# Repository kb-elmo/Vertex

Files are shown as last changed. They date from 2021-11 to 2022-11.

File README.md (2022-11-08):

# Vertex

[][cc-by-nc-sa]<a href="https://ko-fi.com/kb_elmo">kofibadge</a>

### 3D printed Vortex 40% inspired screwless exterior, top-mount keyboard

header

### This design has some flaws!
#### Use at your own risk

---

[STEP files for the case](case/)

[KiCAD PCB files](pcb/)

[Gerbers for PCB production](pcb/gerbers/)

[JLCPCB BOM](pcb/fab/vertex_bom_jlc.csv)

[JLCPCB CPL](pcb/fab/vertex_cpl_jlc.csv)

[Vial-QMK firmware](firmware/)

---

This work is licensed under a
[Creative Commons Attribution-NonCommercial-ShareAlike 4.0 International License][cc-by-nc-sa].

[][cc-by-nc-sa]

[cc-by-nc-sa]: http://creativecommons.org/licenses/by-nc-sa/4.0/
[cc-by-nc-sa-image]: https://licensebuttons.net/l/by-nc-sa/4.0/88x31.png
[cc-by-nc-sa-shield]: https://img.shields.io/badge/License-CC%20BY--NC--SA%204.0-lightgrey.svg

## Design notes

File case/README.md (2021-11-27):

# Vertex case

### These files are meant for 3D printing only! 

They are not suitable for CNC machining and trying to use them for that will most likely result in failure of the parts.

For assembly you need 4x m2x10mm screws for the case and 8x m2x8mm screws to mount the plate.  
The three pieces that make the bottom half of the case have tabs on the sides for glueing them together.  
It's not strictly necessary to do this but it helps with the overall rigidity of the case assembly.

---

### Supported layouts

Right now there is only one plate available.  
More alternative options will be added later.

The currently supported layout looks like this.
layout1

<!--Plate 2  
<img src="https://i.imgur.com/FzC2Qn9.png" alt="layout2"/>

Plate 3  
<img src="https://i.imgur.com/ZxjCJdc.png" alt="layout3"/>
-->

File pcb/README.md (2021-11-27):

# Vertex PCB

### Features

- Powered by an Atmega32u2
- Basic ESD and overvoltage protection
- USB type-C port for a detachable cable
- Multiple layout options (see below)
- Fully programmable using [QMK](https://qmk.fm) and [Vial](https://get.vial.today)

---

### Supported layouts

layout1

The two different lengths spacebars can be swapped.

---

### Preview

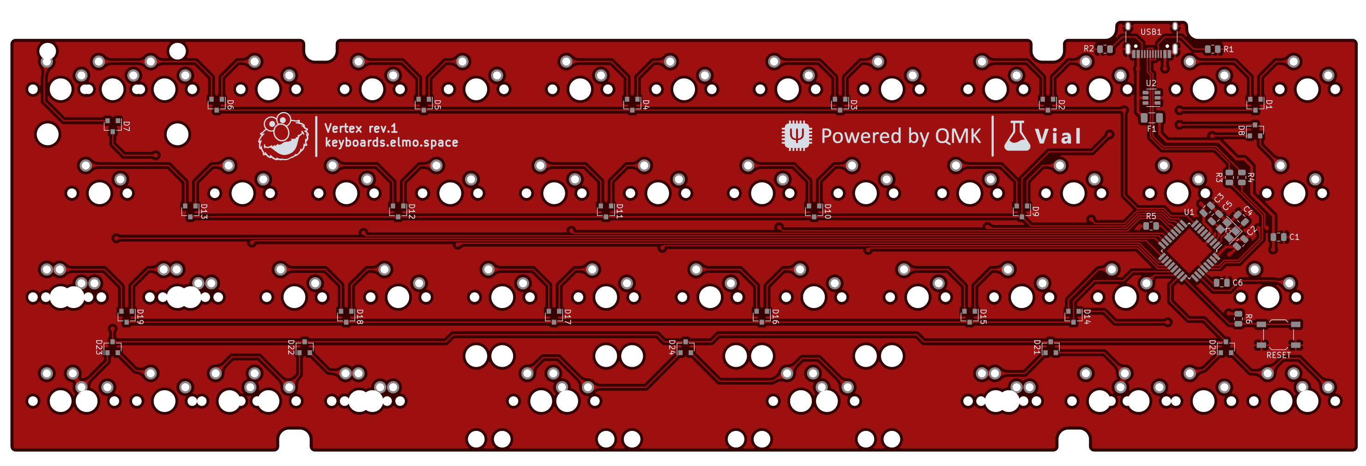
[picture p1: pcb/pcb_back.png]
pcb_back

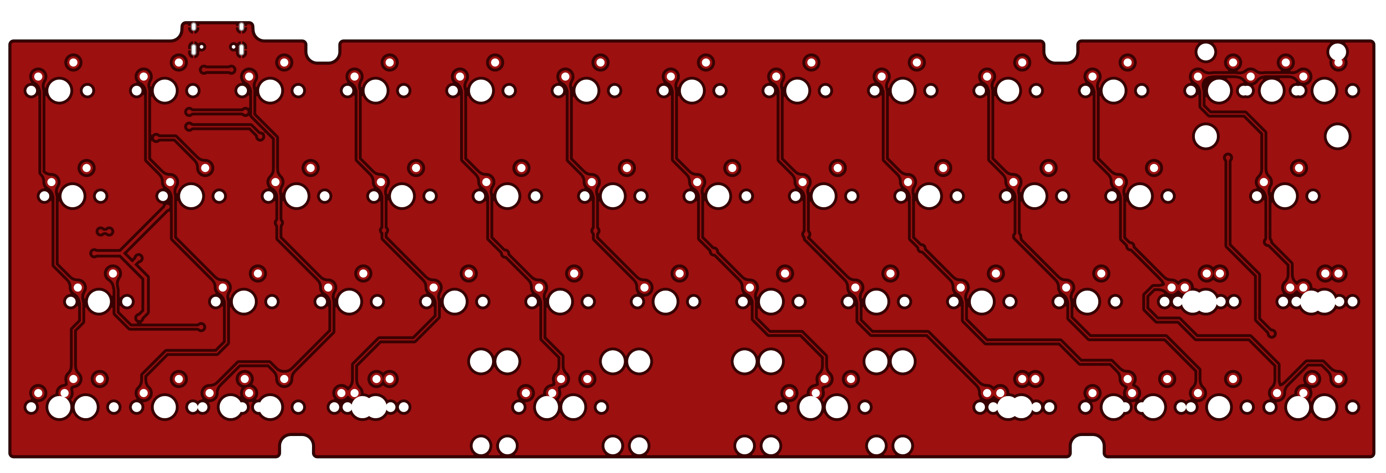
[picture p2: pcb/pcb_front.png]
pcb_front


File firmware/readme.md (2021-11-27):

# Vertex

vertex

3D printed Vortex 40% inspired screwless exterior, top-mount keyboard

* Keyboard Maintainer: [kb-elmo](https://github.com/kb-elmo)
* Hardware Supported: Vertex rev.1
* Hardware Availability: [Open source project](https://github.com/kb-elmo/Vertex)

Make example for this keyboard (after setting up your build environment):

    make kb_elmo/vertex:default

Flashing example for this keyboard:

    make kb_elmo/vertex:default:flash

See the [build environment setup](https://docs.qmk.fm/#/getting_started_build_tools) and the [make instructions](https://docs.qmk.fm/#/getting_started_make_guide) for more information. Brand new to QMK? Start with our [Complete Newbs Guide](https://docs.qmk.fm/#/newbs).

## Bootloader

* **Bootmagic reset**: Hold down the top left key and plug in the keyboard
* **Physical reset button**: Briefly press the button labeled "Reset" on the back of the PCB
* **Keycode in layout**: Press the key mapped to `RESET` if it is available

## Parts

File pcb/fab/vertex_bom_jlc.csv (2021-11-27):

Comment | Designator | Footprint | LCSC Part #
10uF | C1 | C_0805_2012Metric | C91245
0.1uF | C2,C3 | C_0805_2012Metric | C49678
22pF | C4,C5 | C_0805_2012Metric | C1804
1uF | C6 | C_0805_2012Metric | C28323
D_Small | D5,D4,D3,D2,D6,D8,D12,D11,D10,D9,D13,D14,D18,D17,D16,D15,D19,D20,D22,D21,D23,D24,D7,D1 | D_SOT-23_ANK_norm | C68978
Polyfuse_Small | F1 | Fuse_1206_3216Metric | C69688
5.1k | R1,R2 | R_0805_2012Metric | C27834
22 | R3,R4 | R_0805_2012Metric | C17561
10k | R5,R6 | R_0805_2012Metric | C17414
SW_Push | RESET | SW_SPST_TL3342 | C318884
ATmega32U2-AU | U1 | TQFP-32_7x7mm_P0.8mm | C618733
SRV05-4 | U2 | SOT-23-6 | C85364
USB_C_Receptacle_USB2.0 | USB1 | USB_C_Receptacle_HRO_TYPE-C-31-M-12 | C165948
Crystal_GND24_Small | X1 | Crystal_SMD_3225-4Pin_3.2x2.5mm | C13738

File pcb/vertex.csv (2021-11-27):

Comment | Designator | Footprint | LCSC
10uF | C1 | Capacitor_SMD:C_0805_2012Metric | C91245
0.1uF | C2,C3 | Capacitor_SMD:C_0805_2012Metric | C49678
22pF | C4,C5 | Capacitor_SMD:C_0805_2012Metric | C1804
1uF | C6 | Capacitor_SMD:C_0805_2012Metric | C28323
D_Small | D1,D2,D3,D4,D5,D6,D7,D8,D9,D10,D11,D12,D13,D14,D15,D16,D17,D18,D19,D20,D21,D22,D23,D24 | custom_parts:D_SOT-23_ANK_norm | C68978
Polyfuse_Small | F1 | Fuse:Fuse_1206_3216Metric | C69688
MX-NoLED | MX14,MX37,MX39,MX40,MX43,MX44,MX66 | MX_Only:MXOnly-1.25U-NoLED
MX-NoLED | MX1,MX2,MX3,MX4,MX5,MX6,MX7,MX8,MX9,MX10,MX11,MX12,MX13,MX15,MX16,MX17,MX18,MX19,MX20,MX21,MX22,MX23,MX24,MX27,MX28,MX29,MX30,MX31,MX32,MX33,MX34,MX35,MX36,MX46,MX47,MX48,MX49,MX50,MX51,MX52,MX53,MX67 | MX_Only:MXOnly-1U-NoLED
MX-NoLED | MX25,MX26 | MX_Only:MXOnly-1.75U-NoLED
MX-NoLED | MX38,MX45 | MX_Only:MXOnly-1.5U-NoLED
MX-NoLED | MX41,MX54 | MX_Only:MXOnly-2.75U-ReversedStabilizers-NoLED
MX-NoLED | MX42,MX55 | MX_Only:MXOnly-2.25U-ReversedStabilizers-NoLED
MX-NoLED | MX60 | MX_Only:MXOnly-2U-NoLED
5.1k | R1,R2 | Resistor_SMD:R_0805_2012Metric | C27834
22 | R3,R4 | Resistor_SMD:R_0805_2012Metric | C17561
10k | R5,R6 | Resistor_SMD:R_0805_2012Metric | C17414
SW_Push | RESET1 | Button_Switch_SMD:SW_SPST_TL3342 | C318884
ATmega32U2-AU | U1 | Package_QFP:TQFP-32_7x7mm_P0.8mm | C618733
SRV05-4 | U2 | Package_TO_SOT_SMD:SOT-23-6 | C85364
USB_C_Receptacle_USB2.0 | USB1 | Connector_USB:USB_C_Receptacle_HRO_TYPE-C-31-M-12 | C165948
Crystal_GND24_Small | X1 | Crystal:Crystal_SMD_3225-4Pin_3.2x2.5mm | C13738

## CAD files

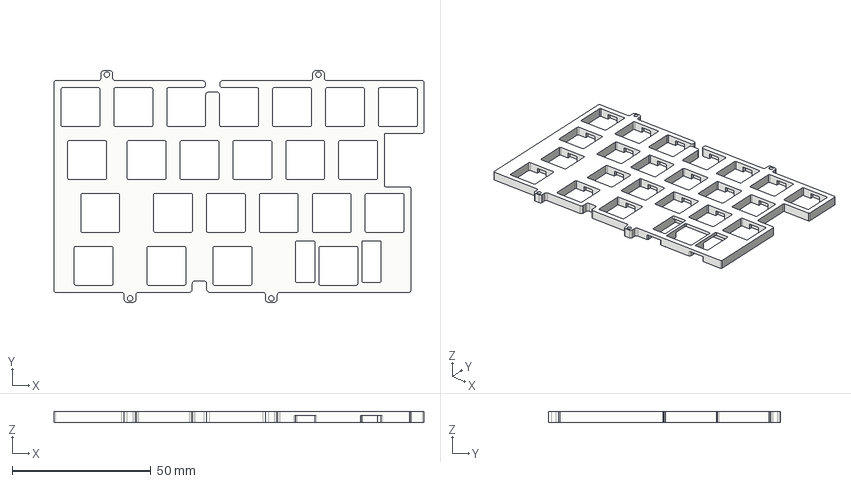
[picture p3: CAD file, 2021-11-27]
case/plate_left.step
133.2 x 83.4 x 4.00 mm

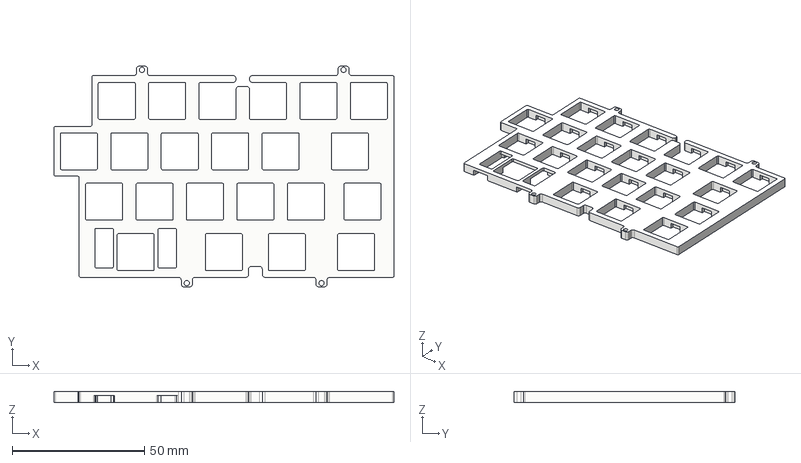
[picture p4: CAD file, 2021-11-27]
case/plate_right.step
128.5 x 83.4 x 4.00 mm

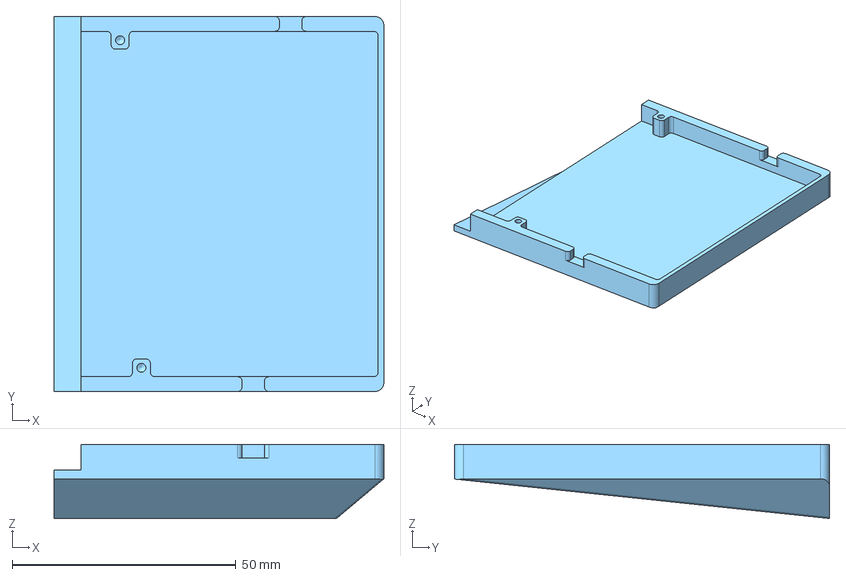
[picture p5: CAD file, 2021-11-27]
case/bottom_right.step
73.7 x 83.8 x 16.5 mm

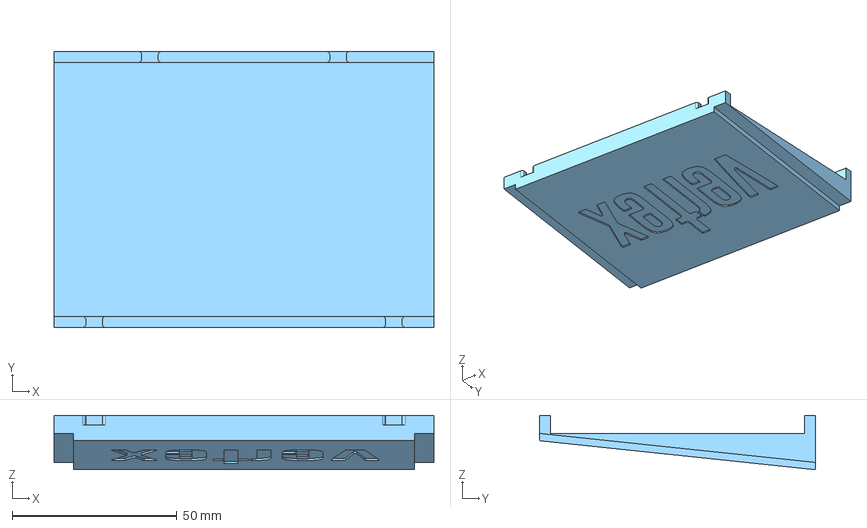
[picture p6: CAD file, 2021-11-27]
case/bottom_center.step
115.5 x 83.8 x 16.5 mm

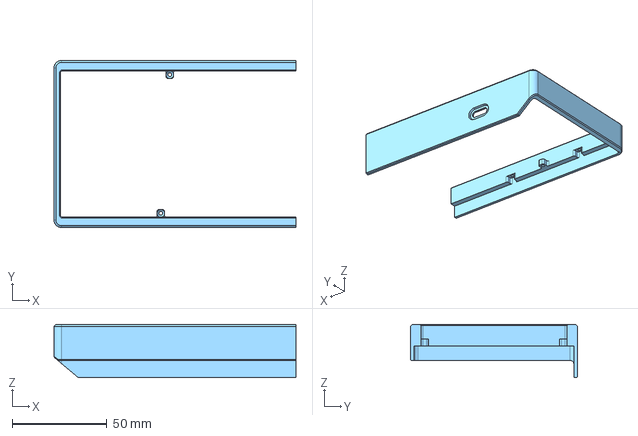
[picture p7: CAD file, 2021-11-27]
case/top_left.step
127.7 x 88.2 x 28.0 mm

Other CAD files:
case/bottom_left.step
case/top_right.step

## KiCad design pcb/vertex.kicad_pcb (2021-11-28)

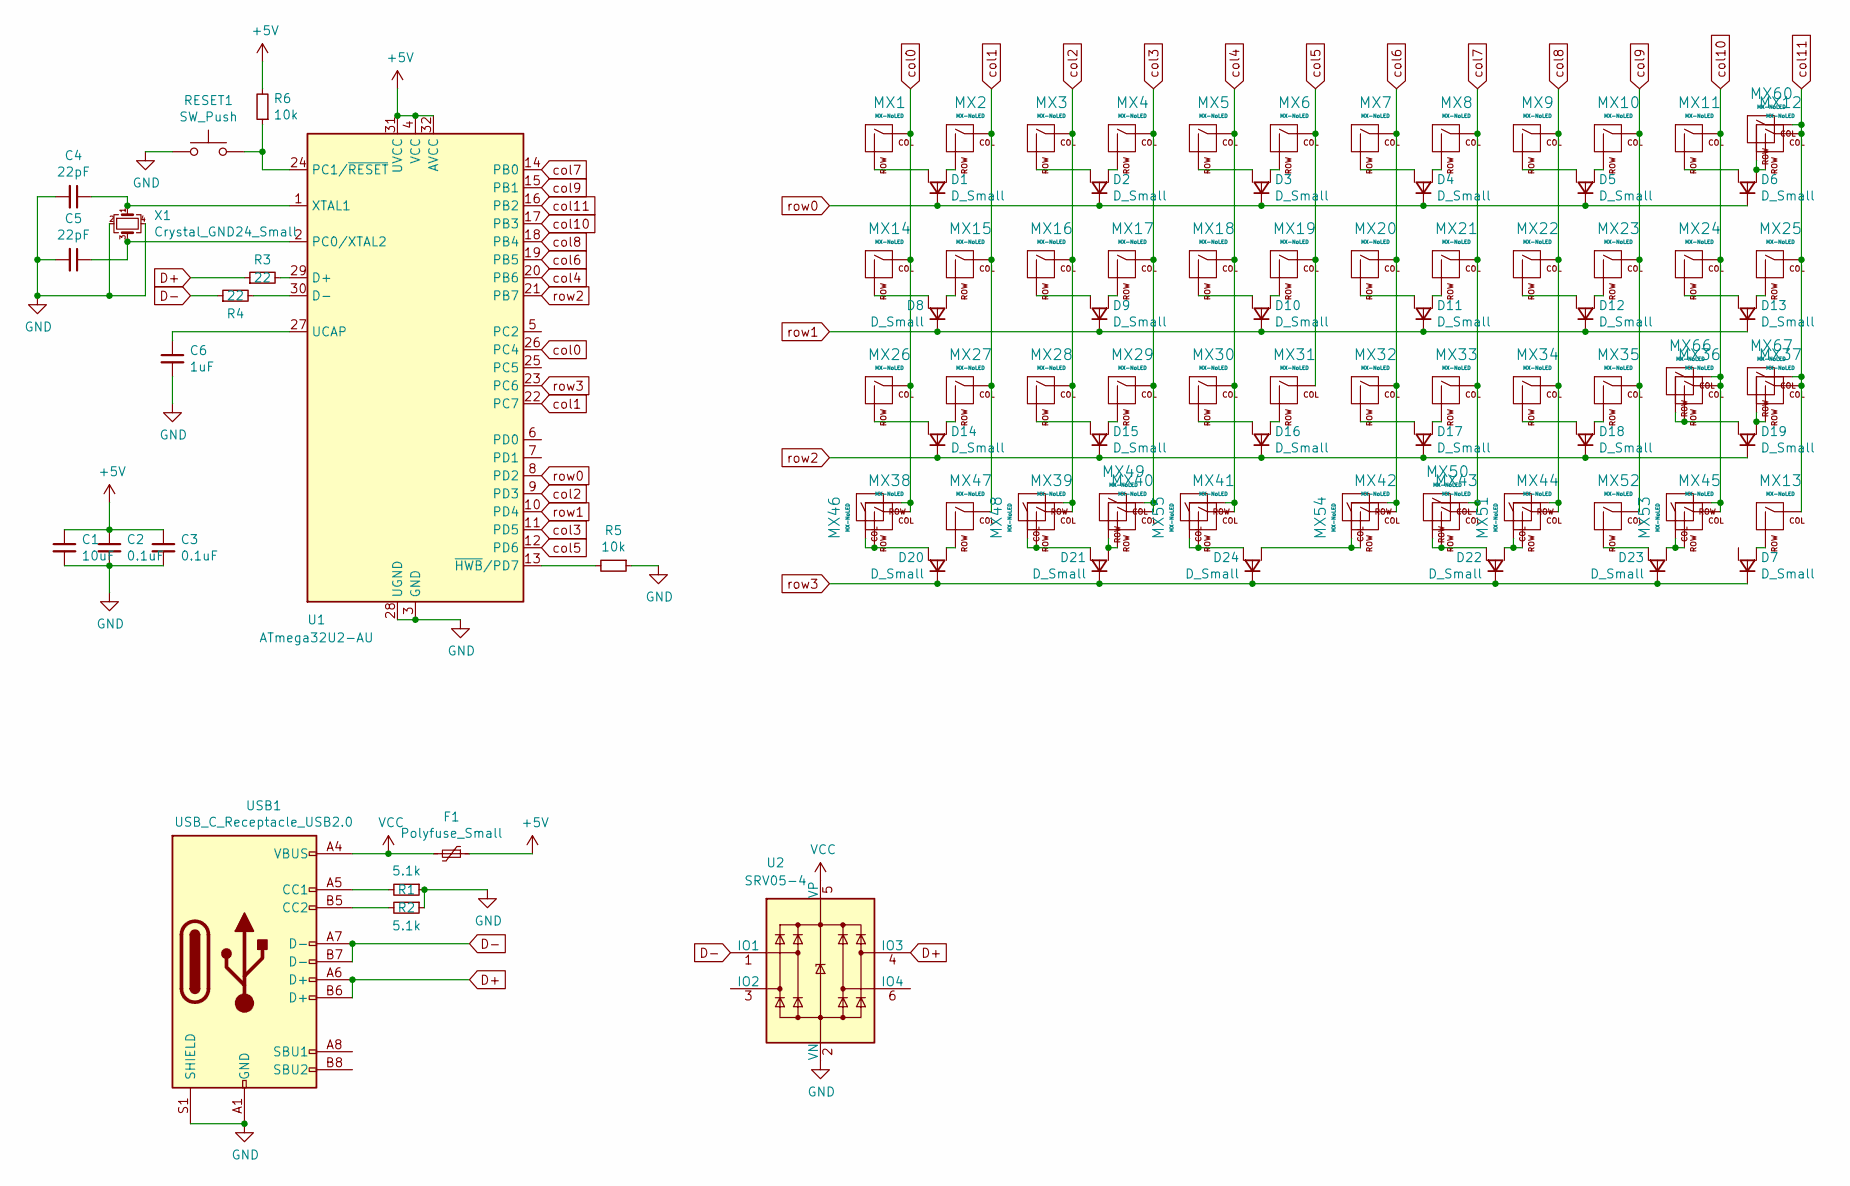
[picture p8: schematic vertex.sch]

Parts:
C1: 10uF; C_0805_2012Metric; LCSC C91245
C2, C3: 0.1uF; C_0805_2012Metric; LCSC C49678
C4, C5: 22pF; C_0805_2012Metric; LCSC C1804
C6: 1uF; C_0805_2012Metric; LCSC C28323
D1, D2, D3, D4, D5, D6, D7, D8, D9, D10, D11, D12, D13, D14, D15, D16, D17, D18, D19, D20, D21, D22, D23, D24: D_Small; D_SOT-23_ANK_norm; LCSC C68978
F1: Polyfuse_Small; Fuse_1206_3216Metric; LCSC C69688
MX1, MX2, MX3, MX4, MX5, MX6, MX7, MX8, MX9, MX10, MX11, MX12, MX13, MX15, MX16, MX17, MX18, MX19, MX20, MX21, MX22, MX23, MX24, MX27, MX28, MX29, MX30, MX31, MX32, MX33, MX34, MX35, MX36, MX46, MX47, MX48, MX49, MX50, MX51, MX52, MX53, MX67: MX-NoLED; MXOnly-1U-NoLED
MX14, MX37, MX39, MX40, MX43, MX44, MX66: MX-NoLED; MXOnly-1.25U-NoLED
MX25, MX26: MX-NoLED; MXOnly-1.75U-NoLED
MX38, MX45: MX-NoLED; MXOnly-1.5U-NoLED
MX41, MX54: MX-NoLED; MXOnly-2.75U-ReversedStabilizers-NoLED
MX42, MX55: MX-NoLED; MXOnly-2.25U-ReversedStabilizers-NoLED
MX60: MX-NoLED; MXOnly-2U-NoLED
R1, R2: 5.1k; R_0805_2012Metric; LCSC C27834
R3, R4: 22; R_0805_2012Metric; LCSC C17561
R5, R6: 10k; R_0805_2012Metric; LCSC C17414
RESET1: SW_Push; SW_SPST_TL3342; LCSC C318884
U1: ATmega32U2-AU; TQFP-32_7x7mm_P0.8mm; LCSC C618733
U2: SRV05-4; SOT-23-6; LCSC C85364
USB1: USB_C_Receptacle_USB2.0; USB_C_Receptacle_HRO_TYPE-C-31-M-12; LCSC C165948
X1: Crystal_GND24_Small; Crystal_SMD_3225-4Pin_3.2x2.5mm; LCSC C13738

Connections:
+5V: C1.1, C2.1, C3.1, F1.1, R6.2, U1.4 (VCC), U1.31 (UVCC), U1.32 (AVCC)
D+: R3.1, U2.4 (IO3), USB1.A6 (D+), USB1.B6 (D+)
D-: R4.1, U2.1 (IO1), USB1.A7 (D-), USB1.B7 (D-)
GND: C1.2, C2.2, C3.2, C4.2, C5.2, C6.2, R1.1, R2.1, R5.1, RESET1.1, U1.3 (GND), U1.28 (UGND), U2.2 (VN), USB1.A1 (GND), USB1.A12 (GND), USB1.B1 (GND), USB1.B12 (GND), USB1.S1 (SHIELD), X1.2, X1.4; also elsewhere on the board
unnamed: C4.1, U1.1 (XTAL1), X1.1
unnamed: C5.1, U1.2 (PC0/XTAL2), X1.3
unnamed: C6.1, U1.27 (UCAP)
unnamed: D1.2 (A1), MX1.2 (ROW)
unnamed: D1.3 (A2), MX2.2 (ROW)
unnamed: D2.2 (A1), MX3.2 (ROW)
unnamed: D2.3 (A2), MX4.2 (ROW)
unnamed: D3.2 (A1), MX5.2 (ROW)
unnamed: D3.3 (A2), MX6.2 (ROW)
unnamed: D4.2 (A1), MX7.2 (ROW)
unnamed: D4.3 (A2), MX8.2 (ROW)
unnamed: D5.2 (A1), MX9.2 (ROW)
unnamed: D5.3 (A2), MX10.2 (ROW)
unnamed: D6.2 (A1), MX11.2 (ROW)
unnamed: D6.3 (A2), MX12.2 (ROW), MX60.2 (ROW)
unnamed: D7.3 (A2), MX13.2 (ROW)
unnamed: D8.2 (A1), MX15.2 (ROW)
unnamed: D8.3 (A2), MX14.2 (ROW)
unnamed: D9.2 (A1), MX16.2 (ROW)
unnamed: D9.3 (A2), MX17.2 (ROW)
unnamed: D10.2 (A1), MX18.2 (ROW)
unnamed: D10.3 (A2), MX19.2 (ROW)
unnamed: D11.2 (A1), MX20.2 (ROW)
unnamed: D11.3 (A2), MX21.2 (ROW)
unnamed: D12.2 (A1), MX22.2 (ROW)
unnamed: D12.3 (A2), MX23.2 (ROW)
unnamed: D13.2 (A1), MX24.2 (ROW)
unnamed: D13.3 (A2), MX25.2 (ROW)
unnamed: D14.2 (A1), MX26.2 (ROW)
unnamed: D14.3 (A2), MX27.2 (ROW)
unnamed: D15.2 (A1), MX28.2 (ROW)
unnamed: D15.3 (A2), MX29.2 (ROW)
unnamed: D16.2 (A1), MX30.2 (ROW)
unnamed: D16.3 (A2), MX31.2 (ROW)
unnamed: D17.2 (A1), MX32.2 (ROW)
unnamed: D17.3 (A2), MX33.2 (ROW)
unnamed: D18.2 (A1), MX34.2 (ROW)
unnamed: D18.3 (A2), MX35.2 (ROW)
unnamed: D19.2 (A1), MX36.2 (ROW), MX66.2 (ROW)
unnamed: D19.3 (A2), MX37.2 (ROW), MX67.2 (ROW)
unnamed: D20.2 (A1), MX47.2 (ROW)
unnamed: D20.3 (A2), MX38.2 (ROW), MX46.1 (COL)
unnamed: D21.2 (A1), MX40.2 (ROW), MX49.2 (ROW)
unnamed: D21.3 (A2), MX39.2 (ROW), MX48.1 (COL)
unnamed: D22.2 (A1), MX44.2 (ROW), MX51.1 (COL)
unnamed: D22.3 (A2), MX43.2 (ROW), MX50.2 (ROW)
unnamed: D23.2 (A1), MX45.2 (ROW), MX53.1 (COL)
unnamed: D23.3 (A2), MX52.2 (ROW)
unnamed: D24.2 (A1), MX42.2 (ROW), MX54.1 (COL)
unnamed: D24.3 (A2), MX41.2 (ROW), MX55.1 (COL)
unnamed: R1.2, USB1.A5 (CC1)
unnamed: R2.2, USB1.B5 (CC2)
unnamed: R3.2, U1.29 (D+)
unnamed: R4.2, U1.30 (D-)
unnamed: R5.2, U1.13 (~HWB~/PD7)
unnamed 60: R6.1, RESET1.2, U1.24 (PC1/~RESET); also elsewhere on the board
VCC: F1.2, U2.5 (VP), USB1.A4 (VBUS), USB1.A9 (VBUS), USB1.B4 (VBUS), USB1.B9 (VBUS)
col0: MX1.1 (COL), MX14.1 (COL), MX26.1 (COL), MX38.1 (COL), MX46.2 (ROW), U1.26 (PC4)
col1: MX2.1 (COL), MX15.1 (COL), MX27.1 (COL), MX47.1 (COL), U1.22 (PC7)
col2: MX3.1 (COL), MX16.1 (COL), MX28.1 (COL), MX39.1 (COL), MX48.2 (ROW), U1.9 (PD3)
col3: MX4.1 (COL), MX17.1 (COL), MX29.1 (COL), MX40.1 (COL), MX49.1 (COL), U1.11 (PD5)
col4: MX5.1 (COL), MX18.1 (COL), MX30.1 (COL), MX41.1 (COL), MX55.2 (ROW), U1.20 (PB6)
col5: MX6.1 (COL), MX19.1 (COL), MX31.1 (COL), U1.12 (PD6)
col6: MX7.1 (COL), MX20.1 (COL), MX32.1 (COL), MX42.1 (COL), MX54.2 (ROW), U1.19 (PB5)
col7: MX8.1 (COL), MX21.1 (COL), MX33.1 (COL), MX43.1 (COL), MX50.1 (COL), U1.14 (PB0)
col8: MX9.1 (COL), MX22.1 (COL), MX34.1 (COL), MX44.1 (COL), MX51.2 (ROW), U1.18 (PB4)
col9: MX10.1 (COL), MX23.1 (COL), MX35.1 (COL), MX52.1 (COL), U1.15 (PB1)
col10: MX11.1 (COL), MX24.1 (COL), MX36.1 (COL), MX45.1 (COL), MX53.2 (ROW), MX66.1 (COL), U1.17 (PB3)
col11: MX12.1 (COL), MX13.1 (COL), MX25.1 (COL), MX37.1 (COL), MX60.1 (COL), MX67.1 (COL), U1.16 (PB2)
row0: D1.1 (K), D2.1 (K), D3.1 (K), D4.1 (K), D5.1 (K), D6.1 (K), U1.8 (PD2)
row1: D8.1 (K), D9.1 (K), D10.1 (K), D11.1 (K), D12.1 (K), D13.1 (K), U1.10 (PD4)
row2: D14.1 (K), D15.1 (K), D16.1 (K), D17.1 (K), D18.1 (K), D19.1 (K), U1.21 (PB7)
row3: D7.1 (K), D20.1 (K), D21.1 (K), D22.1 (K), D23.1 (K), D24.1 (K), U1.23 (PC6)

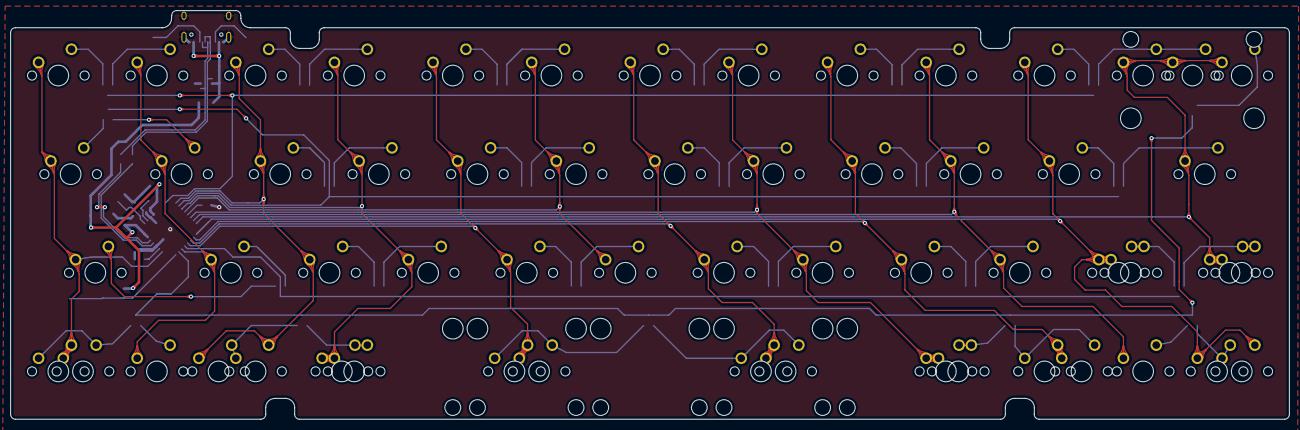
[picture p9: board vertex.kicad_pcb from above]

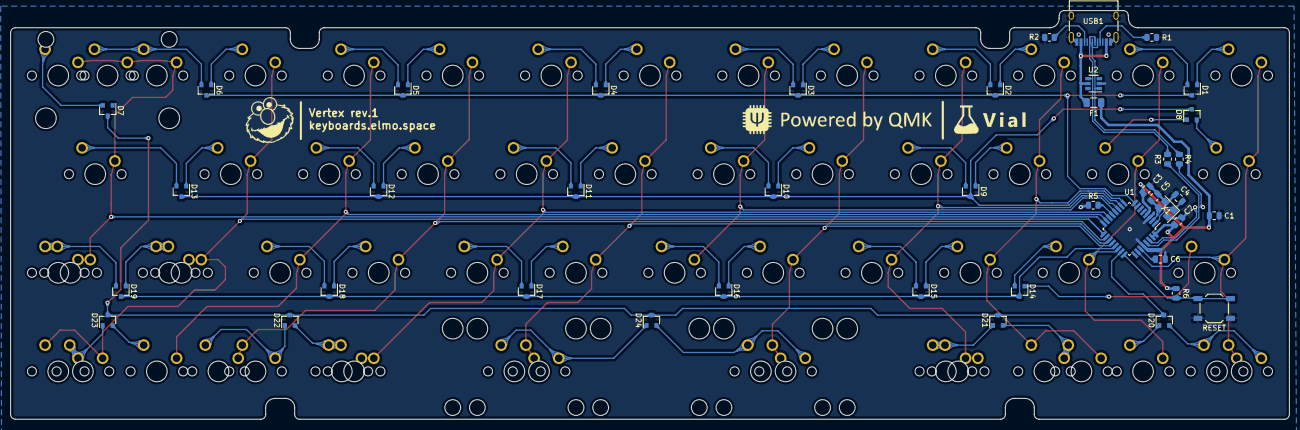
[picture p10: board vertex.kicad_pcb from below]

Board: 2 copper layers, 247.0 x 78.9 mm, 100 parts (42 on the bottom side), 77 nets.

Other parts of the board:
RESET: SW_Push; SW_SPST_TL3342

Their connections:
GND: RESET.1; also elsewhere on the board
unnamed 60: RESET.2; also elsewhere on the board

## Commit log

2021-09-06 PCB finalized
    [vertex-B_Cu.gbr, vertex-B_Mask.gbr, vertex-B_Paste.gbr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]
2021-09-16 finalized PCB
    [vertex-B_Cu.gbr, vertex-B_Mask.gbr, vertex-B_Paste.gbr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]
2021-11-27 finalize repo layout
    [bottom_center.step, bottom_left.step, bottom_right.step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]
2021-11-27 update gerbers
    [vertex-B_Cu.gbr, vertex-B_Mask.gbr, vertex-B_Paste.gbr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]

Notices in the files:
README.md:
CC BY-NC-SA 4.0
